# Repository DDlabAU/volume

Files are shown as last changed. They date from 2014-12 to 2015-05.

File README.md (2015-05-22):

volume
======

Ultrasound based amp control, runs on an arduino, controls the power on the stereo at the lab.
The arduino code has devolved into an ugly unreadable collection of hacks, with filters, delays and weirdness.. It works.. but clone it at your own risk.

Controlling the volume is no longer a feature, since the interface was bothersome and counterintuitive, so no it's just on-off control.. which makes the name of the project kind of weird :D

Components
==========

  * Input: An [HRLV-MaxSonar MB1013](http://www.maxbotix.com/Ultrasonic_Sensors/MB1013.htm)
  * Output: An [RGB LED from sparkfun](https://www.sparkfun.com/products/105) (for visual feedback of which 'zone' the user is in)
  * ~~Volume control: A continuous rotation RC servo [like this one](https://www.sparkfun.com/products/9347)~~
  * Power control: 9 gram servo [like this one](http://www.hobbyking.com/hobbyking/store/__662__HXT900_9g_1_6kg_12sec_Micro_Servo.html)

Zone?!
======

There are ~~four~~ two "zones" above the table (beneath the ultrasound sensor) which represent ~~4~~ 2 different states:

Measured from the table, we have:

1. 0-50 cm: Deadzone: Nothing happens here.
  * LED colour: RED if stereo is (supposed to be) off.
  * LED colour: ~~White~~ Green if stereo is (supposed to be) on.
2. ~~50-80 cm: Volume down zone: Hold your hand here to turn the volume down.~~
  * ~~LED colour: Yellow .. ish.~~
3. ~~80-120 cm: Volume up zone: Hold your hand here to turn the volume up.~~
  * ~~LED colour: Green.~~
4. >120 cm: Power toggle zone: Hold your hand here to turn the stereo on/off.
  * LED colour: Blue.
  * Cooldown period: 5 seconds.

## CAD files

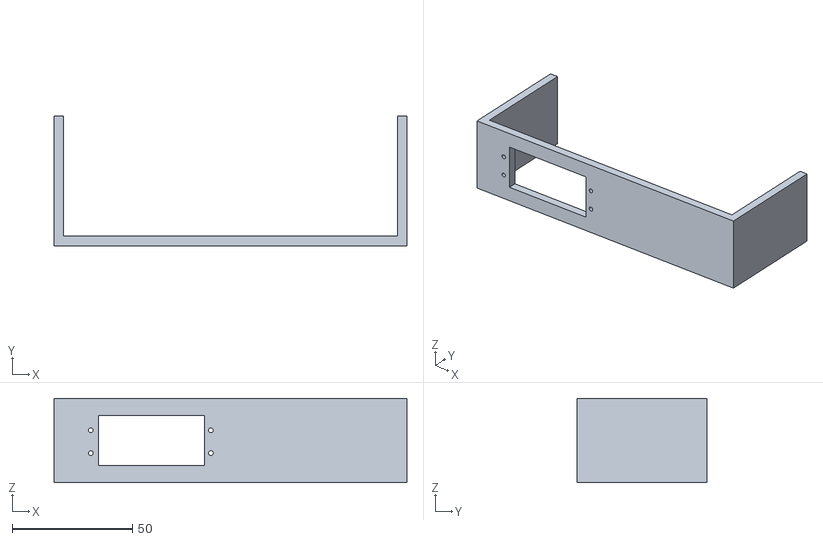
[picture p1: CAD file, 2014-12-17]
3D/volume.stl
147.0 x 54.0 x 35.0

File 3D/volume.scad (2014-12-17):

inside_width=139;
grab_length=50;
height=35;
fatness=4;
$fn=25;
servo_width=21;
servo_length=42;
servo_spline_offset=9.66;

  translate([0,0,0]){
  	difference()
  	{
  	union(){

  			rotate([90,0,0]){cube([inside_width+2*fatness,height,fatness]);}
  			rotate([90,0,90]){color("lime"){cube([grab_length,height,fatness]);}}
  			translate([inside_width+fatness,0,0]){rotate([90,0,90]){color("red"){cube([grab_length,height,fatness]);}}}
  			}


		translate([25-servo_spline_offset,fatness/2,height/2-servo_width/2]){
			rotate([90,0,0 ]){
 		translate([0,servo_width/2-servo_width/4,0])
 		{

		cylinder(r=1,h=fatness*2);
		translate([0,9.5,0]){cylinder(r=1,h=fatness*2);}
		translate([50,0,0]){cylinder(r=1,h=fatness*2);}
		translate([50,9.5,0]){cylinder(r=1,h=fatness*2);}
	    }
		translate([4.25-1,0,0]){cube([servo_length+2,servo_width,2*fatness]);}}}



	}
}

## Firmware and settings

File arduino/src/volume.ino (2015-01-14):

static unsigned int volumeServoZero=45;
static unsigned int volumeServoUp=38;
static unsigned int volumeServoDown=50;
static unsigned int powerServoUnpressed=90;
static unsigned int powerServoPressed=60;
static unsigned int filter_alpha = 5;
static unsigned int redPin=3;
static unsigned int greenPin=6;
static unsigned int bluePin=5;
static unsigned int volumeServoPin = 9;
static unsigned int powerServoPin = 10;
static unsigned int powerToggleCooldown=5000;
static unsigned int powerToggleSluggishness=800;
#include <Servo.h>

Servo volumeServo, powerServo;

int pingPin = A0;

boolean stereoIsOn=false;
boolean sluggishnessArmed=true;
long lastToggleTime=0;
long sluggishnessStarttime=0;


enum interface_states { //default state should be "get_data"
	inactive,
	volume_down,
	volume_up,
	toggle_power
};

interface_states state;

void setup()
{
	Serial.begin(115200);

	powerServo.attach(powerServoPin);
	volumeServo.attach(volumeServoPin);

	volumeServo.write(volumeServoZero);

	pinMode(pingPin, INPUT);
	pinMode(redPin, OUTPUT);
	pinMode(greenPin, OUTPUT);
	pinMode(bluePin, OUTPUT);
}

	unsigned int ping=255;

	//store 3 preceding readings to calculate change over time.
	int lastPing=0;
	int lastLastPing=0;
	int lastLastLastPing=0;
	int sumOfChanges=0;
	static int allowablePingOffset=1;
	unsigned long rolloverTimeout=25; //time it takes between iterations of loading values into the "last ping" integer set
	unsigned long millisAtLastRollover=0;

	boolean allowStateChange=false;

void loop()
{
  //moving average filter:
  ping = (ping * filter_alpha + analogRead(pingPin)) / (filter_alpha+1);
   //ping=analogRead(pingPin);

  //check that change in ping isn't too steep to allow state change.

  //it kind of looks like i am doing the same thing (low pass filtering) twice, but i need to store the last couple of values in order to determine the rate of change.
  if(millis()-rolloverTimeout>millisAtLastRollover)
  {
  	lastLastLastPing=lastLastPing;
  	lastLastPing=lastPing;
  	lastPing=ping;

	sumOfChanges=(lastLastPing-lastLastLastPing)+(lastPing-lastLastPing)+(ping-lastPing);

  	millisAtLastRollover=millis();

  	Serial.print("lastLastLastPing: ");
  	Serial.println(lastLastLastPing);
  	Serial.print("lastLastPing: ");
  	Serial.println(lastLastPing);
  	Serial.print("lastPing: ");
  	Serial.println(lastPing);
  	Serial.print("Sum of changes: ");
  	Serial.println(sumOfChanges);
  	Serial.print("ping: ");
  	Serial.println(ping);
  	Serial.println();
  	Serial.print("Change allowed: ");
  	if(allowStateChange) Serial.println("TOTALLY!");
  	else Serial.println("NOT!");
  }

  /*
  if(sumOfChanges==0) allowStateChange=true;
  else allowStateChange=false;
*/

  if(sumOfChanges>allowablePingOffset) allowStateChange=false;
  else if (sumOfChanges<(-1*allowablePingOffset)) allowStateChange=false;
  else allowStateChange=true;

if (allowStateChange)
{
  if(ping>10) state=toggle_power;
  if(ping>70) state=volume_up;
  if(ping>140) state=volume_down;
  if(ping>180) state=inactive;
}
/*
  Serial.print("ping graph: ");
  for(int i = 0; i<ping/2;i++) Serial.print('-');
  Serial.print("| ");
  Serial.println(ping);
*/



switch(state)
{
	case volume_down:
		sluggishnessArmed=true;
		setcolour(255,40,0);
		volumeServo.write(volumeServoDown);
		break;

	case volume_up:
		sluggishnessArmed=true;
		setcolour(0,255,0);
		volumeServo.write(volumeServoUp);
		break;

	case toggle_power:
		setcolour(0,0,255);
		volumeServo.write(volumeServoZero);

		if(sluggishnessArmed)
			{
				sluggishnessStarttime=millis();
				sluggishnessArmed=false;
			}


		if (millis()-sluggishnessStarttime>powerToggleSluggishness)
		{

		if(millis()-lastToggleTime>powerToggleCooldown)
			{
				onOff();
				sluggishnessArmed=true;
				lastToggleTime=millis();
			}
		}
		break;

	case inactive:
		sluggishnessArmed=true;
		volumeServo.write(volumeServoZero);
		if(stereoIsOn) setcolour(255,255,255); //white
		else setcolour(255,0,0); //red
		break;
}

 //standby_light();
  //onOff();
  //delay(1000);
  //volumeServo.write(volumeServoDown);
}


void setcolour(int red,int green,int blue)
{
	analogWrite(redPin,red);
	analogWrite(greenPin,green);
	analogWrite(bluePin,blue);
}

void pulse_colour(int red,int green,int blue,int delaytime)
{
int i;


    for(i=0;i<255;i++)
    {
    	setcolour(map(red, 0, 255, 0, i),map(green, 0, 255, 0, i),map(blue, 0, 255, 0, i));
    	delay(delaytime);
    }

    for(i=255;i>0;i--)
    {
    	setcolour(map(red, 0, 255, 0, i),map(green, 0, 255, 0, i),map(blue, 0, 255, 0, i));
    	delay(delaytime);
    }


    setcolour(0,0,0);
}

void standby_light()
{
	pulse_colour(255,0,0,25);
  	delay(2000);
}

void onOff()
{
stereoIsOn=!stereoIsOn; //invert power state

powerServo.write(powerServoPressed);
delay(150);
powerServo.write(powerServoUnpressed);
}

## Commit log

2014-12-17 moved some stuff
    [volume.scad, volume.stl]
2015-01-14 added another delay, this one gives som sluggishness to the power-toggle
2015-01-14 calibrated the power-toggle-sliggishness, and made sure timer was reset when needed
    [volume.ino]
2015-05-22 removed (commented out) the volume servo, and volume functions, because only on/off is really useful
